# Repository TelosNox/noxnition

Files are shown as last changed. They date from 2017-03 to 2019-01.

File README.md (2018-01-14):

# Feuerwerk Zündmodul + Android App
Selbstbauprojekt für Funkzündmodule

## Zielgruppe
Das Projekt richtet sich an interessierte Privatmenschen mit technischen Kenntnissen, die gerne elektrisch ihr Silvesterfeuerwerk zünden wollen.
Man sollte wissen, wie man grundsätzlich einen Schaltplan liest und wie man an Bauteilen die passenden Pins erkennt (Datenblatt). Und man sollte mit dem Lötkolben umgehen können.

Dieses Projekt richtet sich NICHT an Profis. Wer etwas für professionelle Einsatzzwecke sucht, ist hier leider falsch.
Dennoch darf natürlich gerne reingeschaut werden.

## Eckdaten
#### Zündmodul
- Funkzündmodul mit n x 8 Kanälen
- Manuelle Scharfschaltung
- Elektrische Scharfschaltung
- Durchgangsprüfung der Zünder
- Zündspannung 12V max 7A, Prüfstrom 1,2mA
- Kommunikation über WiFi (WPA gesichert)
- Einfache API über HTTP
#### Android App
- Automatische suche von Modulen
- Direkte Einzelbedienung (Scharfschalten, Durchgangsprüfung, Zündung)
- Feuerwerksplanung mit virtuellen Kanälen (Zusammenfassung mehrerer Kanäle auch unterschiedlicher Module unter einem Namen)
- Ablaufplanung mit Zeitverzögerungen (Sekundenbereich)
- Semiautomatisches Schießen des Feuerwerks

## Motivation
Das Projekt entstand durch mehrere Faktoren. Einerseits war ich gerade für den Kettenheizöler Noxmatic mit dem NodeMCU am experimentieren, andererseits hatte ich gerade ein Silvester hinter mir, an dem wir viele Batterien hatte aber diese manuell zündeten.
Ich hatte die Nase voll vom hin und herlaufen und den Pausen dazwischen. Ich hatte Bock darauf, mein Feuerwerk mal elektisch zu zünden. Keinen Bock hingegen hatte ich daruf, für eine kleine 4 Kanal China Zündanlage schon mindestens 40€ hinzulegen zumal ich ja wusste, wie billig man schon den NodeMCU und die als Treiber nötigen Komponenten bekommt.
Ich hatte auch Bock darauf, sowas mal selbst zu entwickeln, also brachte ich die Idee im Feuerwerk Forum (www.feuerwerk-forum.de) mal zur Sprache und bekam dort viele hilfreiche Ratschläge von Mitgliedern, die elektrotechnisch noch einiges fitter sind, als ich. Für diese Hilfe bin ich sehr Dankbar, denn bei einer Zündanlage geht es auch um Sicherheit und da sollte man nicht am falschen Ende sparen.

## Die Idee
Ich wollte eine Zündanlage für den Selbstbau entwickeln, die möglichst einfach und möglichst günstig nachzubauen und zu bedienen ist. Dabei sollte sie möglichst offen für Erweiterungen sein.
Kommuniziert wird über WLAN, das Protokoll ist HTTP und als Fernsteuerung dient einfach ein beliebiges Android Gerät (hat eigentlich jeder zu Hause).

## Entstehung des Zündmoduls
Ursprünglicher Plan war, dass ein Zündmodul genau 8 Kanäle + eine elektrische Scharfschaltung hat. Der NodeMCU hat genau 9 schaltbare digitale Ausgänge, das reicht für die 8 Kanäle sowie den einen Ausgang für die Scharfschaltung.
An die Ausgänge einfach direkt MosFet als Low Side Schalter dran (ohne weitere Beschaltung) und die Scharfschaltung ebenso als Low Side Schalter für die Gesamtmasse.

Hat so leider nicht funktioniert.
Also gab es folgende Schritte, die zum aktuellen Schaltplan geführt haben.

#### MosFet ordentlich beschalten
Da hier pyrotechnische Gegenstände zum Einsatz kommen, von denen eine gewisse Gefahr ausgeht, muss die Treiberschaltung ordentlich sein. Daher war es gegeben, die MosFet mit einer ordentlichen Schaltung zu versehen.

#### Scharfschaltung mit Low Side Schalter geht nicht
Man kann nicht die Masse eines Low Side MosFet wieder als Busspannung für einen anderen Low Side MosFet verwenden. Das funktioniert so einfach nicht. Also musste eine High Side Schaltung mit einem P-MosFet her. Damit der NodeMCU das aber korret ansteuern kann, wird trotzdem noch ein Low Side gebraucht. Somit war ein zusätzlicher MosFet und Widerstände nötig.
Da P-MosFet keinen so tollen Innenwiderstand wie N-MosFet haben ist der zusätzliche MosFet auch leider nicht ganz so billig.

#### Der NodeMCU zappelt
Leider leider hat so ein NodeMCU 3 Pins, die beim booten kurz zappeln. Die elektrische Scharfschaltung verhindert, dass beim Einschalten irgendwas passieren kann. Wenn allerdings Scharf geschalten ist und dann der Controller einen Reset durchführt, zappeln die Pins und es liegt kurz Zündspannung an.
Meine A-Zünder haben beim Versuch nicht ausgelöst. Trotzdem war das zu unsicher.
Da keine weiteren Pins verfügbar waren und eine Anlage mit nur 5 Kanälen wenig Sinn macht, wurde das Schieberegister hinzugefügt. Somit war das n x 8 Modul geboren, denn die Schaltung erlaubt es jetzt beliebig viele Schieberegister hintereinander zu reihen und so ein beliebiges vielfaches von 8 Kanälen umzusetzen.
Ich selbst habe mir Module mit 8 und 16 Kanälen gebaut.

#### Zu viel Strom!
Da so ein Zünder quasi einen Kurzschluss darstellt und auch Parallelschaltungen von Zündern funktionieren sollen ohne dass Akku oder MosFet abrauchen, wurde noch eine Strombegrenzung eingeführt. Das ist ein simpler großer 10W Draht Keramik Lastwiderstand mit 1,8Ohm. Somit liegt der maximal mögliche Strom bei nominal 12V Spannung (real dann knapp 13) bei ca. 7A.
Natürlich kann das nicht als Dauerstrom betrieben werden. Der P-MosFet erhitzt sich. Für Dauerstrom bräuchte er eine Kühlung.
Der Lastwiderstand ist mit den so anliegenden gut 70W ebenso überfordert, kann das über kurze Zeiträume aber über Wärme abpuffern.
Wen man ganz Safe gehen will, kann man den Widerstand auf 5,6Ohm erhöhen. Damit liegt der Strom bei 2,3A und die Leistung bei 25W. Größere Parallelschaltungen könnten dann aber schwierig werden.

Ergänzt man das alles jetzt noch mit der Spannungsmessung und ein paar Schaltern sowie LEDs und Terminals, kommt man zu dem Schaltplan, der schließlich entstanden ist und umgesetzt wurde.

## Aufbau des Zündmoduls
### Bauteile (Basis)
Die folgenden Bauteile sind nötig, um überhaupt die Grundlage des Moduls zu bilden. Sie bleiben immer gleich, egal wieviele Kanäle man umsetzt.
- 1x NodeMCU V3 (Lolin)
- 2x Kippschalter (am besten unterschiedlich, so dass man Hauptschalter von Zündschalter unterscheiden kann)
- 1x Draht Keramik Lastwiderstand 1,8Ohm 10Watt (R1)
- 1x IRF9540N (Elektrische Scharfschaltung)
- 1x IRF3708 (Elektrische Scharfschaltung)
- 5x R 10k
- 1x R 4,7k
- 2x R 1k
- 1x C 100nF
- 3x LED 12V (Rot, Gelb, Grün)
- 1x Bleiakku 12v (z.B. Ultracell UL1.3-12 den verwende ich)
- 2x Kabelschuhe zum Anschluss des Akkus
- Ausreichend Draht zum verbinden (Mehrfarbig ist Hilfreich) - 0,5mm Querschnitt für Haupt und Zündleitungen, Steuerleitungen dürfen kleiner sein
- Flexible Litze für den Akku und sonstige bewegliche Teile (es ist praktisch, wenn man die Platine aus dem Gehäuse nehmen kann, um bei Bedarf Software aufzuspielen)

### Bauteile je 8 Kanäle
Die folgenden Bauteile sind nötig, um jeweils 8 Kanäle umzusetzen. Diese kann man beliebig vervielfachen.
- 1x 74HC595 (Schieberegister)
- 8x R 100
- 8x R 10k
- 8x Anschlussterminal (Lautsprecherklemmen z.B.)

Will man 16 Kanäle umsetzen, dann braucht man das einfach doppelt, bei 24 Kanäle 3x etc..

### Schaltplan Erläuterung
Hier findet ihr den [Schaltplan](Hardware/KiCad/Zündanalage_Neu/Schematic.pdf)

Ich bin kein Profi, was KiCad angeht, daher ist sicherlich nicht alles optimal.
Für die Schalter hatte ich kein Bauteil gefunden. Daher die gestrichelte Linie und den entprechenden Namen (Hauptschalter, Zündschalter).
Verbunden ist bei Überkreuzungen nur das, was einen Punkt hat.
Die Schieberegister hatten keinen Pin für Vcc, daher ist da ein extra Punkt eingezeichnet und benannt. Das muss an den entsprechenden Pin angeschlossen werden.
Der Schaltplan zeigt den Aufbau für 16 Kanäle. Will man nur 8 Kanäle umsetzen, so lässt man das rechte Schieberegister und alle daran angeschlossenen Treiber einfach weg. Die Leitung, die auf Pin 9 ankommt, muss dann stattdessen beim linken Schieberegister auf Pin 9 angeschlossen werden.
Warum?
Die Schieberegister sind seriell durchgeschleift, indem der serielle Ausgang (Pin 9) des ersten Registers an den Eingang (Pin 14) des nächsten Registers geht. Das LETZTE Register geht dann wieder zurück zum Controller. Will man noch mehr Schieberegister nutzen, so fügt man sie nach diesem Schema einfach zwischen die beiden Register des Schaltplans ein.
Alle anderen Datenleitungen sind als Bus ausgeführt. An jedem Register kommt das selbe an.
Dadurch, dass das letzte Register (bei 8 Kanälen ist das auch das Erste) diesen Ausgang an den Controller zurückgibt, kann der Controller zählen, wieviele Kanäle vorhanden sind. Mit diesem Trick funktioniert die selbe Software mit beliebig vielen Registern. Es wäre sogar möglich, ein einzelnes größeres Register zu verwenden, solange die gleichen Eigenschaften vorliegen.

### Aufbau
Für das Zündmodul gibt es keine vorgefertigte Platine. Es bietet sich an, die Bauteile auf Lochraster zu löten.
Zu aller erst sollte man sich Gedanken machen, wo und wie man alle Bauteile platziert.
Generelle Strategie: An einem Ende Controller und Basisbeschaltung zusammen. Dann mittig Schieberegister und am anderen Ende die MosFet mit Widerstanden.

Wenn man Schritt für Schritt vorgehen will, lötet man zunächst nur den Basisaufbau (nicht übersehen, dass die LED vom Zündschalter auf Masse geht, die Leitung läuft durch die ganzen Treiber). Die rote LED ist für den Hauptschalter gedacht, die gelbe für den Zündkreisschalter und die Grüne zeigt Zündbereitschaft an. Wer möchte mann auch die grüne LED als EIN/AUS nutzen und die rote LED als Warnfarbe für Zündbereitschaft. Die Anleitung geht davon aus, dass Rot für EIN/AUS benutzt wird und beschreibt entsprechend.
Temporär muss man jetzt D2 und D3 (über den vorhandenen 1k Widerstand) überbrücken. Dann kann man Software aufspielen und testen. Die LEDs sollten schon korrekt reagieren (Power LED beim Hauptschalter, Zünd LED beim Zündschalter und die Zündleitungs LED bei Scharfschaltung). Anmerkung: Die Zündleitungs LED leuchtet bei eingeschalteter Power LED schwach. Das ist normal, da Prüfspannung auf der Zündleitung anliegt.
Ebenso sollte die Spannungsanzeige in der App funktionieren (etwa Nennspannung bei eingeschalteter Zündung und ansonsten 2-3V).

Falls an dieser Stelle irgendwas nicht wie beschrieben geht: Fehler suchen.

Anschließend ist es praktisch die MosFet jeweils in Reihen zu setzen, so dass man die Massebeine direkt aufeinander löten kann. Aber Platz lassen, da müssen noch Widerstände hin. Die ebenfalls einlöten, so dass nur noch das Schaltsignal am R100 Widerstand fehlt und der Ausgang zum Anschlussterminal.
Zuletzt die Schieberegister platzieren und verlöten. Nicht vergessen: Die Brücke zwischen D2 und D3 aufmachen und an den Registern korrekt anschließen.

## Bedienung des Zündmoduls
Am Zündmodul gibt es nur 2 Schalter und 3 Leds.
Der Zündkreisschalter sollte beim Einschalten immer ausgeschalten sein (Sicherheit). Dann den Hauptschalter umlegen.
Die rote LED leuchtet, um den Betriebszustand EIN anzuzeigen. Die grüne Zündkreis LED leuchtet schwach (das lässt sich nicht verhindern bzw. wäre nur mit zusätzlichem Aufwand lösbar), das ist normal.
Jetzt ist das Modul Betriebsbereit. Der Zündkreisschalter wird erst dann umgelegt, wenn alle Zünder fertig angeschlossen sind und man sich vergewissert hat, dass die elektrische Scharfschaltung AUS ist (mittels App). Auch die Durchgangsprüfung sollte man sicherheitshalber immer mit ausgeschaltenem Zündkreisschalter machen.

### Konfiguration
Das Modul versucht sich ca. 30sec lang automatisch mit dem konfigurierten WiFi zu verbinden (initial ist noch nichts konfiguriert). Findet es kein passendes Netz, wird es automatisch selbst zum AccessPoint. Per default gelten folgende Daten:
- ssid = "noxnition"
- passwort = "noxnition"
- ip = 192.168.0.128
Das kann im ino Script vorm Einspielen der Software geändert werden.

Nun verbindet man sich mit dem Modul über WiFi, so kann man im Browser einfach die IP des Moduls aufrufen. Es erscheint eine kleine Webseite, mit der das Modul konfiguriert werden kann.
Einzustellen sind:
- Modulname
- SSID
- Passwort

SSID und Passwort beziehen sich hier auf das WiFi, zu dem das Modul sich verbinden soll. Der Modulname MUSS bei Verwendung der App eindeutig sind. Wenn mehrere Module verwendet werden, unterscheidet die App sie anhand ihres Namens.

### Kommunikation
Ist das Modul konfiguriert und loggt sich in ein WiFi ein, so schaltet es in den Bereitschaftsmodus. Jetzt können über HTTP die Funktionen aufgerufen werden.

Allgemein werden alle Aktionen über HTTP GET gesteuert. Für das Feuern eines Kanals wird der Kanal als Parameter übergeben.
Die Antwort ist immer ein simpler Text in Form von Properties.

#### Status
Mit einem HPPT GET und dem Pfad "state" wird der Status abgerufen. Beispiel: `GET http://192.168.0.128/state`
Als Antwort erhält man Spannung und Zündzustand.
- voltage=12.6
- a=1

#### Zündbereitschaft EIN
Mit einem HPPT GET und dem Pfad "arm" wird Zündbereitschaft aktiviert. Beispiel: `GET http://192.168.0.128/arm`
Als Antwort erhält man operation=1 einen Misserfolg gibt es hier nicht.

#### Zündbereitschaft AUS
Mit einem HPPT GET und dem Pfad "disarm" wird Zündbereitschaft aktiviert. Beispiel: `GET http://192.168.0.128/disarm`
Als Antwort erhält man operation=1 einen Misserfolg gibt es hier nicht.

#### Kanal zünden
Mit einem HTTP GET und dem Pfad "fire" wird ein Kanel gezündet. Als Parameter "channel" ist die Kanalnummer zu übergeben. Beispiel: `GET http://192.168.0.128/fire?channel=6`
Als Antwort erhält man Bestätigung und den gefeuerten Kanal
- operation=1
- channel=6

#### Durchgangsprüfung durchführen
Mit einem HTTP GET und dem Pfad "check" wird auf allen Kanälen auf Durchgang geprüft. Beispiel: `GET http://192.168.0.128/check`
Die Anlage stellt nun sicher, dass sie NICHT Zündbereit ist und prüft zusätzlich die anliegende Zündspannung. Geht hier etwas schief, so kommt operation=0 zurück, um den Fehler anzuzeigen. Ansonsten kommt operation=1 und für jeden Kanal die Info, ob er Durchgang hat
- operation=1
- c1=0
- c2=1
- c3=1
- etc...

#### Modulkonfiguraton abfragen
Mit einem HPPT GET und dem Pfad "getConfig" wird die Modulkonfiguration abgefragt. Beispiel: `GET http://192.168.0.128/getConfig`
Als Antwort erhält man den Modulnamen und die Anzahl Kanäle
- name=Fiffi
- channels=16

#### Modul finden
Da die Module über DHCP eine IP bekommen und diese dem Sender somit nicht zwingend bekannt ist, können Module per Broadcast gefunden werden. Jedes Modul reagiert auf UDP Broadcast und sendet als Antwort an den Absender ein UDP Paket mit einer Antwort, wie bei den HTTP Requests. Sie enthält Modulname, Kanäle und den Inhalt der Broadcast Nachricht (zur Identifikation des Requests, wenn zyklisch gepollt wird)-
- name=Fiffi
- channels=16
- request=broadcast135213 (in der Regel sendet man irgend einen Zufallswert oder zählt sequenziell hoch)

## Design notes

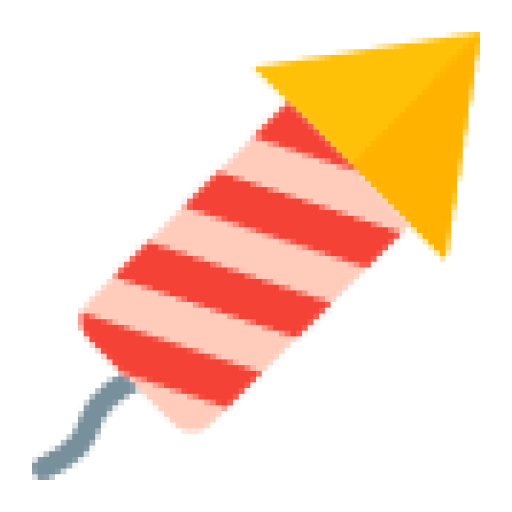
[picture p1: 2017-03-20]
Android/Noxnition/ic_launcher-web.png

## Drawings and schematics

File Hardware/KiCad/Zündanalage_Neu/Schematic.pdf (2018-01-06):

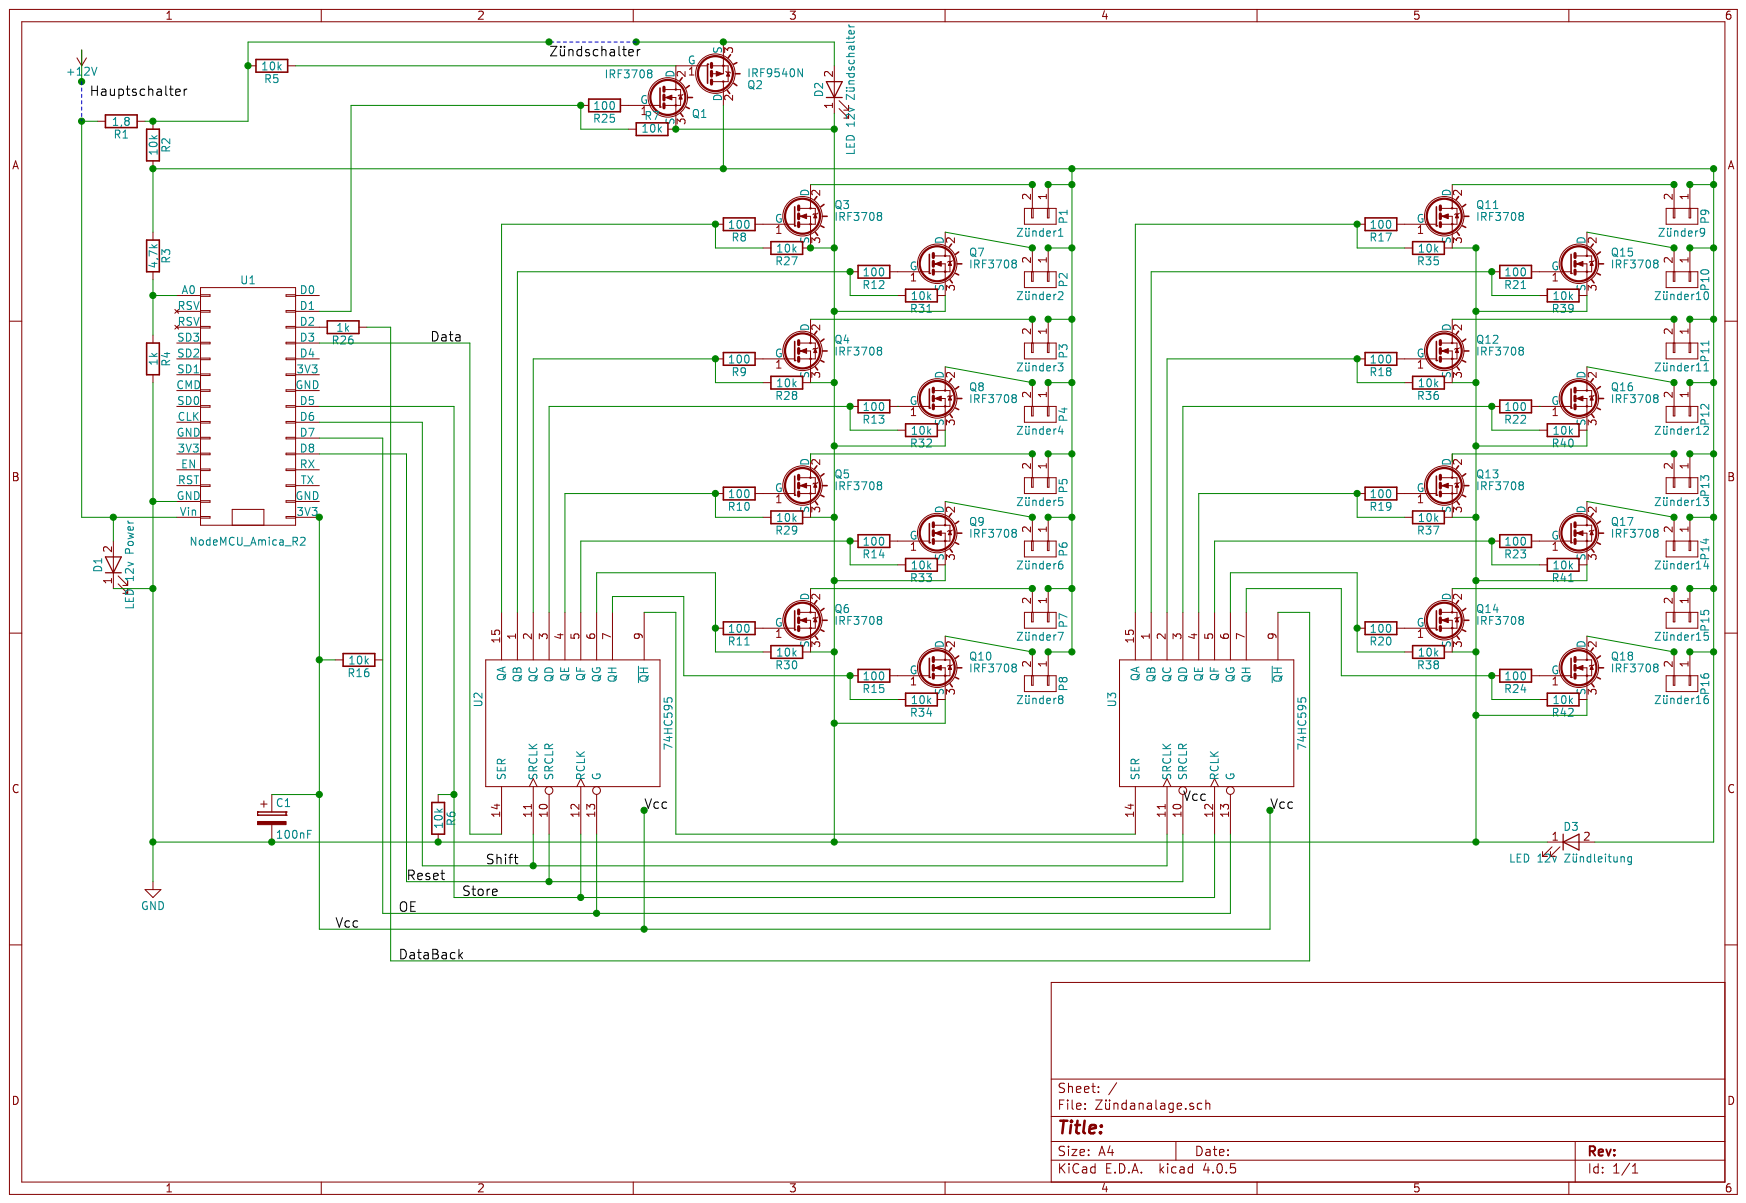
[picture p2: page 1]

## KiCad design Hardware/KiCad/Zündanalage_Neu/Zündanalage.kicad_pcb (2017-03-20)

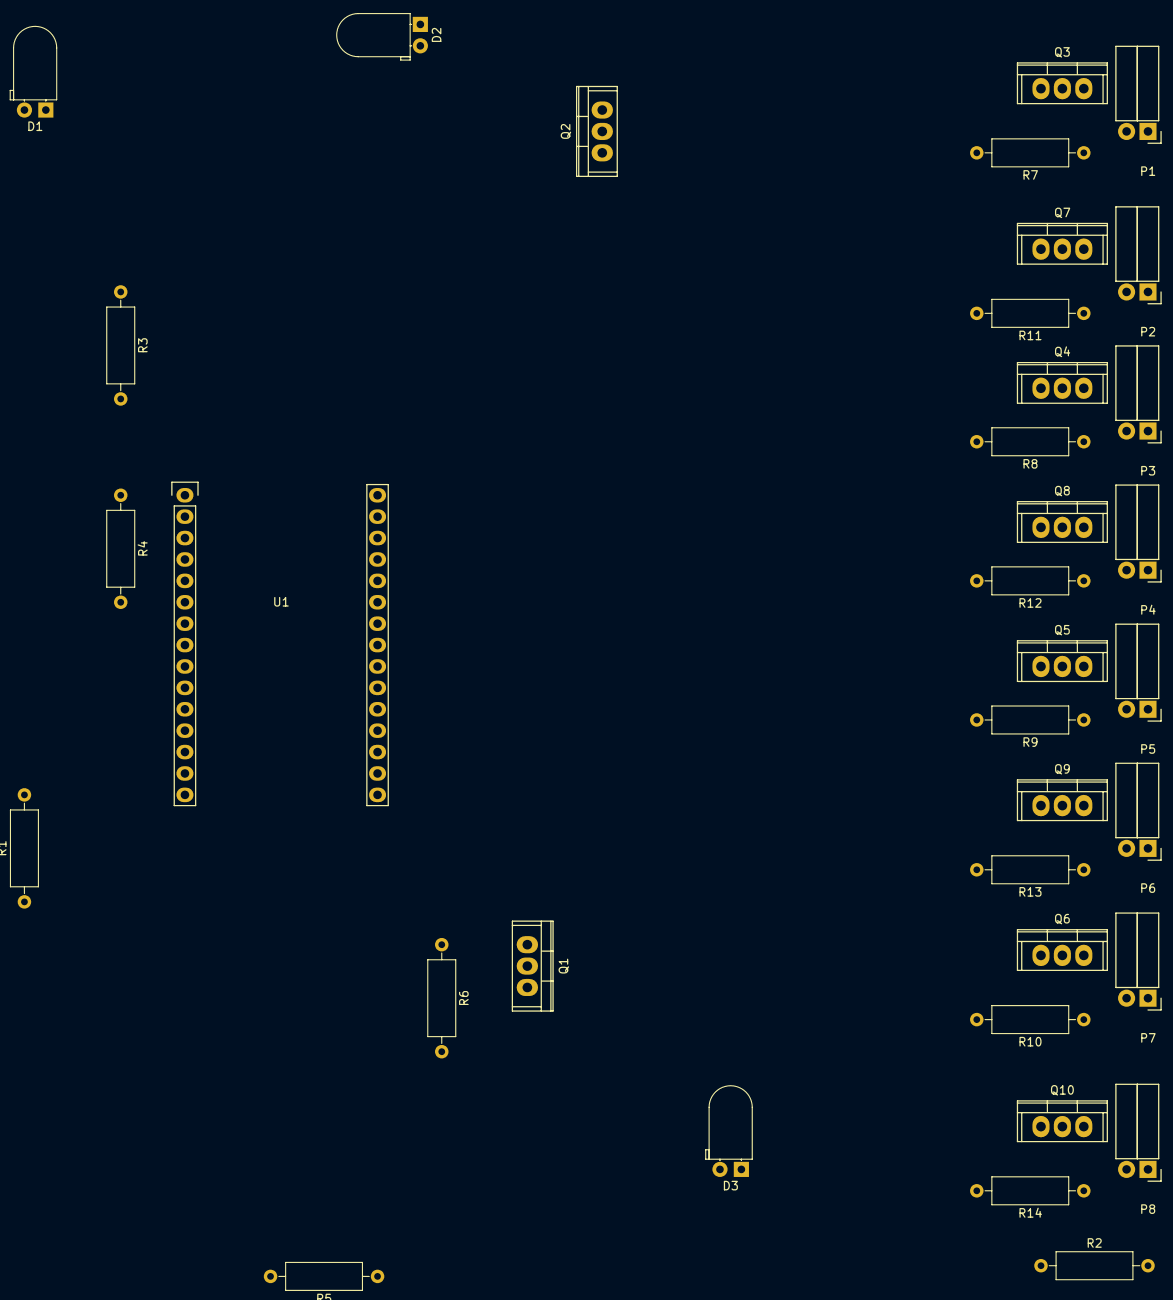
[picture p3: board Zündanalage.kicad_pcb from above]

Board: 2 copper layers, 36 parts (0 on the bottom side), 24 nets, no tracks yet.

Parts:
D1: LED 12v Power; LED_D5.0mm_Horicontal_O1.27mm
D2: LED 12v Zündschalter; LED_D5.0mm_Horicontal_O1.27mm
D3: LED 12v Zündleitung; LED_D5.0mm_Horicontal_O1.27mm
P1: Zünder1; Socket_Strip_Angled_1x02
P2: Zünder2; Socket_Strip_Angled_1x02
P3: Zünder3; Socket_Strip_Angled_1x02
P4: Zünder4; Socket_Strip_Angled_1x02
P5: Zünder5; Socket_Strip_Angled_1x02
P6: Zünder6; Socket_Strip_Angled_1x02
P7: Zünder7; Socket_Strip_Angled_1x02
P8: Zünder8; Socket_Strip_Angled_1x02
Q1, Q3, Q4, Q5, Q6, Q7, Q8, Q9, Q10: IRF3708; TO-220
Q2: IRF9540N; TO-220
R1: 1,8; R_Axial_DIN0309_L9.0mm_D3.2mm_P12.70mm_Horizontal
R2, R5, R6, R7, R8, R9, R10, R11, R12, R13, R14: 10k; R_Axial_DIN0309_L9.0mm_D3.2mm_P12.70mm_Horizontal
R3: 4,7k; R_Axial_DIN0309_L9.0mm_D3.2mm_P12.70mm_Horizontal
R4: 1k; R_Axial_DIN0309_L9.0mm_D3.2mm_P12.70mm_Horizontal
U1: NodeMCU_Amica_R2

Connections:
GND: D1.1, D2.1, D3.1, Q1.3, Q3.3, Q4.3, Q5.3, Q6.3, Q7.3, Q8.3, Q9.3, Q10.3, R4.2, R6.2, R7.1, R8.1, R9.1, R10.1, R11.1, R12.1, R13.1, R14.1, U1.14
unnamed: D1.2, R1.2, U1.15
unnamed: D2.2, Q2.3
unnamed: D3.2, P1.1, P2.1, P3.1, P4.1, P5.1, P6.1, P7.1, P8.1, Q2.2, R2.2, R3.1
unnamed: P1.2, Q3.2
unnamed: P2.2, Q7.2
unnamed: P3.2, Q4.2
unnamed: P4.2, Q8.2
unnamed: P5.2, Q5.2
unnamed: P6.2, Q9.2
unnamed: P7.2, Q6.2
unnamed: P8.2, Q10.2
unnamed: Q1.1, R6.1, U1.22
unnamed: Q1.2, Q2.1, R5.1
unnamed: Q3.1, R7.2, U1.29
unnamed: Q4.1, R8.2, U1.21
unnamed: Q5.1, R9.2, U1.23
unnamed: Q6.1, R10.2, U1.27
unnamed: Q7.1, R11.2, U1.28
unnamed: Q8.1, R12.2, U1.20
unnamed: Q9.1, R13.2, U1.30
unnamed: Q10.1, R14.2, U1.26
unnamed: R1.1, R2.1, R5.2
unnamed: R3.2, R4.1, U1.1

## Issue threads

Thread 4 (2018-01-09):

Geplantes Feuerwerk ohne Aktionen lässt App Abstürzen

TelosNox, 2018-01-09:
Wenn ein geplantes Feuerwerk keine Aktionen hat und man Start drückt, dann stürzt die App ab

TelosNox, 2018-01-14:
Start wird jetzt abgelehnt, wenn keine fire actions existieren

Closed 2018-01-14.

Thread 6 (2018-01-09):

Bereits zugewiesene Triggergruppen nicht mehr anzeigen

TelosNox, 2018-01-09:
Beim Hinzufügen von Triggergruppen zum Abschussplan, werden immer alle Triggergruppen angeboten. Hier sollten nur die auftauchen, die noch nicht hinzugefügt wurden.

TelosNox, 2018-01-14:
Es werden nur noch Triggergruppen angezeigt, die noch nicht zugewiesen sind.

Closed 2018-01-14.

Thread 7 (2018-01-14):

Modulerkennung ändern

TelosNox, 2018-01-14:
Aktuell wird zyklisch ein Broadcast gesendet, um Module zu finden.
Das soll so geändert werden, dass die Modulsuche nur auf Befehl durchgeführt wird. Die Prüfung, ob ein Modul noch online ist, soll über die Statusabfrage erfolgen. Wenn das Modul hier mehrfach nicht reagiert, gilt es als offline.

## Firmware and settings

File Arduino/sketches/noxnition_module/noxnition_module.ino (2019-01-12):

#include <EEPROM.h>
#include <ESP8266WiFi.h>
#include <ESP8266WebServer.h>
#include <WiFiUdp.h>

#define fireTimeMillis 500

const char* config_ssid = "noxnition";
const char* config_password = "noxnition";

const int pinMain = D1;
const int pinData = D3;
const int pinDataBack = D2;
const int pinShift = D6;
const int pinReset = D8;
const int pinOE = D7;
const int pinStore = D5;

ESP8266WebServer server(80);

long *channelTimers = 0;
boolean *channelStates = 0;

String ssid;
String password;
String moduleName;

float voltage;

boolean armed = false;

int channels = 0;

WiFiUDP Udp;
unsigned int localPort = 2390; 
char incomingPacket[255];

void setup() {
  initPins();

  delay(100);

  channels = getChannelCount();
  channelStates = new boolean[channels];
  channelTimers = new long[channels];
  for(int i=0; i < channels; i++) {
    channelTimers[i] = 0;
    channelStates[i] = LOW;
  }

  digitalWrite(pinReset, LOW);

  Serial.begin(115200);
  EEPROM.begin(512);
  delay(10);
  digitalWrite(pinReset, HIGH);
  setRegisterOutput();
  digitalWrite(pinOE, LOW);

  String esid;
  for (int i = 0; i < 32; ++i) {
    esid += char(EEPROM.read(i));
  }
  ssid = esid.c_str();
  Serial.print("SSID: ");
  Serial.println(ssid);
  Serial.println("Reading EEPROM pass");
  String epass = "";
  for (int i = 32; i < 96; ++i) {
    epass += char(EEPROM.read(i));
  }
  password = epass.c_str();
  Serial.print("PASS: ");
  Serial.println(password);  
  Serial.println("Reading EEPROM name");
  String ename = "";
  for (int i = 96; i < 128; ++i) {
    ename += char(EEPROM.read(i));
  }
  Serial.print("NAME: ");
  Serial.println(ename);  

  moduleName = ename.c_str();

  Serial.print("channels: ");
  Serial.println(channels);
  
  // Connect to WiFi network
  Serial.println();

  boolean clientMode = initWifiClient(ssid, password);
  
  Serial.println(WiFi.localIP());
  
  if (!clientMode) {
    Serial.println("AP Mode for Settings");
    initWifiAP();
    initConfigServer();
  } else {
    Serial.println("Module Mode");
    initModuleServer();
  }

  Udp.begin(localPort);
}

void initConfigServer() {
  server.begin();
  server.on("/", settings);
}

void initModuleServer() {
  server.begin();
  server.on("/state", getStatus);
  server.on("/arm", arm);
  server.on("/disarm", disarm);
  server.on("/fire", fire);
  server.on("/check", check);
  server.on("/getConfig", getConfig);
}

void getConfig() {
  String temp = "name=";
  temp += moduleName;
  temp += "\nchannels=";
  temp += channels;
  server.send(200, "application/json", temp);
}

boolean writeSetting(String qsid, String qpass, String qname) {
  if (qsid.length() > 0 && qpass.length() > 0 && qname.length() > 0) {
    Serial.println("clearing eeprom");
    for (int i = 0; i < 128; ++i) { EEPROM.write(i, 0); }
    Serial.println(qsid);
    Serial.println("");
    Serial.println(qpass);
    Serial.println("");
    
    Serial.println("writing eeprom ssid:");
    for (int i = 0; i < qsid.length(); ++i) {
      EEPROM.write(i, qsid[i]);
      Serial.print("Wrote: ");
      Serial.println(qsid[i]); 
    }
    Serial.println("writing eeprom pass:"); 
    for (int i = 0; i < qpass.length(); ++i) {
      EEPROM.write(32+i, qpass[i]);
      Serial.print("Wrote: ");
      Serial.println(qpass[i]); 
    }    
  
    Serial.println("writing eeprom name:"); 
    for (int i = 0; i < qname.length(); ++i) {
      EEPROM.write(96+i, qname[i]);
      Serial.print("Wrote: ");
      Serial.println(qname[i]); 
    }    

    moduleName = qname;
    password = qpass;
    ssid = qsid;
  
    EEPROM.commit();
    return true;
  }
  return false;
}

void settings() {
  String action = server.arg("action");
  String add = "";
  if (action == "save") {
    String qsid = server.arg("ssid");
    String qpass = server.arg("pass");
    String qname = server.arg("name");
    boolean success = writeSetting(qsid, qpass, qname);
    if (success) {
      add += "{\"Success\":\"saved to eeprom... reset to boot into new wifi\"}";
    }
  }
  String temp = getSettingsHtml();
  temp += add;
  server.send(200, "text/html", temp);
}

String getSettingsHtml() {
  String temp = "<html><body><form action=\"\" method=\"post\"><input type=\"hidden\" name=\"action\" id=\"action\" value=\"save\"><table border=\"1\" cellspacing=\"0\"><tr><td>Name</td><td><input type=\"text\" name=\"name\" id=\"name\" maxlength=\"40\" value=\"";
  temp += moduleName;
  temp += "\"></td></tr><tr><td>SSID</td><td><input type=\"text\" name=\"ssid\" id=\"ssid\" maxlength=\"40\" value=\"";
  temp += ssid;
  temp += "\"></td></tr><tr><td>Password</td><td><input type=\"text\" name=\"pass\" id=\"pass\" maxlength=\"40\" value=\"";
  temp += password;
  temp += "\"></td></tr></table><button type=\"submit\">Send</button></form></body></html>";
  return temp;
}

void initPins() {
  pinMode(pinMain, OUTPUT);
  digitalWrite(pinMain, LOW);

  pinMode(pinData, OUTPUT);
  digitalWrite(pinData, LOW);

  pinMode(pinDataBack, INPUT);
  digitalWrite(pinDataBack, LOW);

  pinMode(pinShift, OUTPUT);
  digitalWrite(pinShift, LOW);

  pinMode(pinReset, OUTPUT);
  digitalWrite(pinReset, HIGH);

  pinMode(pinOE, OUTPUT);
  digitalWrite(pinOE, HIGH);

  pinMode(pinStore, OUTPUT);
  digitalWrite(pinStore, LOW);
}

int getChannelCount() {
  digitalWrite(pinReset, LOW);
  digitalWrite(pinReset, HIGH);
  boolean state = LOW;
  int channelCount = 0;
  digitalWrite(pinData, HIGH);
  while(!state) {
    channelCount++;
    digitalWrite(pinShift, LOW);
    digitalWrite(pinShift, HIGH);
    state = digitalRead(pinDataBack);
  }
  digitalWrite(pinData, LOW);
  return channelCount;
}

void initWifiAP() {
  WiFi.disconnect(); 
  WiFi.mode(WIFI_AP);
  IPAddress ip(192,168,0,128);  //Node static IP
  IPAddress gateway(192,168,0,128);
  IPAddress subnet(255,255,255,0);
  WiFi.softAPConfig(ip, gateway, subnet);   // subnet FF FF FF 00
  WiFi.softAP(config_ssid, config_password);
}

boolean initWifiClient(String ssid, String password) {
  WiFi.disconnect(); 
  WiFi.mode(WIFI_STA);
  WiFi.begin(ssid.c_str(), password.c_str());
  int retry = 0;
  while (WiFi.status() != WL_CONNECTED) {
    retry++;
    if (retry > 50) {
      return false;
    }
    delay(500);
  }
  return true;
}

void fire() {
  String channelString = server.arg("channel");
  int channel = channelString.toInt();
  Serial.print("channel to fire: ");
  Serial.println(channel);
  int index = channel-1;
  long fireEnd = millis() + fireTimeMillis;
  channelTimers[index] = fireEnd;
  channelStates[index] = HIGH;
  setRegisterOutput();
  String temp = "operation=1\nchannel=";
  temp += channel;
  server.send(200, "application/json", temp);

}

void setRegisterOutput() {
  digitalWrite(pinStore, LOW);

  for(int i=channels-1; i >= 0; i--) {
    digitalWrite(pinShift, LOW);
    digitalWrite(pinData, channelStates[i]);
    digitalWrite(pinShift, HIGH);
  }
  digitalWrite(pinStore, HIGH);
}

void arm() {
  armInternal(true);

  server.send(200, "application/json", "operation=1");
}

void disarm() {
  armInternal(false);

  server.send(200, "application/json", "operation=1");
}

void armInternal(boolean arm) {
  armed = arm;
  digitalWrite(pinMain, armed);
}

void check() {
  for(int i=0; i < channels; i++) {
    channelStates[i] = LOW;
  }
  setRegisterOutput();
  
  boolean wasArmed = armed;
  if (armed) {
    armInternal(false);
    delay(20);
  }
  int voltageIn = analogRead(A0);
  if (voltageIn > 200) {
    server.send(200, "application/json", "operation=0");
    return;
  }

  if (voltageIn < 50) {
    server.send(200, "application/json", "operation=0");
    return;
  }

  String temp = "operation=1";

  for(int i=0; i < channels; i++) {
    boolean pinState = false;
    temp += "\nc";
    temp += i+1;
    temp += "=";
    int pinVoltageIn = analogRead(A0);
    if (pinVoltageIn > 50) {
      channelStates[i] = HIGH;
      setRegisterOutput();
      delay(5);
      pinVoltageIn = analogRead(A0);
      pinState = pinVoltageIn < 30;
      channelStates[i] = LOW;
      setRegisterOutput();
      delay(5);
    }
    temp += pinState;
  }
  server.send(200, "application/json", temp);
}

void getStatus() {
  String temp = "voltage=";
  temp += voltage;
  temp += "\n";
  temp += "a=";
  temp += armed;

  for(int i=0; i < channels; i++) {
    temp += "\n";
    temp += "c";
    temp += i+1;
    temp += "=";
    temp += channelStates[i];
  }

  server.send(200, "application/json", temp);
}

void processVoltage() {
  static long nextMillis = 0;
  static const float factor = 3.3 * 5.85;

  long currentMillis = millis();
  if (currentMillis > nextMillis) {
    float averageMes = average(analogRead(A0));
    voltage = factor * averageMes / 1024;
    nextMillis = currentMillis + 50;
  }
}

float average(int value) {
  static const int numberOfValues = 10;
  static int values[numberOfValues], counter=0;
  
  int sum=0;
  values[counter] = value;
  for(int i=0; i < numberOfValues; i++) {
    sum += values[i];
  }
  counter++;
  if(counter >= numberOfValues) {
    counter=0;
  }
  return (float) sum / numberOfValues; 
}

void handleFire() {
  long currentMillis = millis();
  for(int i=0; i < channels; i++) {
    long fireEnd = channelTimers[i];
    if (fireEnd != 0 && currentMillis > fireEnd) {
      channelTimers[i] = 0;
      channelStates[i] = LOW;
      setRegisterOutput();
    }
  }
}
 
void loop() {
  int packetSize = Udp.parsePacket();
  if (packetSize) {
    int len = Udp.read(incomingPacket, 255);
    if (len > 0) {
      incomingPacket[len] = 0;
    }
    Serial.println("answer broadcast");
    WiFiClient client;
    if (client.connect(Udp.remoteIP().toString().c_str(), 2410)) {
      String temp = "name=";
      temp += moduleName;
      temp += "\nchannels=";
      temp += channels;
      temp += "\nrequest=";
      temp += incomingPacket;
      client.print(temp);
    }
    client.stop();
  }
  processVoltage();
  handleFire();
  server.handleClient();
}

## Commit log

2017-03-20 Add KiCad sketches
    [Zündanalage.kicad_pcb, Zündanalage.sch]
2017-12-23 Broadcast fix + Semi automatic mode
    commit missing files
    [noxnition_module.ino]
2018-01-03 Rework persistence, some UI and Bugfix
    - Persistence now uses JSON, so it is easier to change/enhance
    - Planned Firework is not accessed by button anymore. Instead the main
    screen is swiped
    - Add capability to retry ignition in planned firework if ignition
    command is not confirmed
2018-01-05 Rework Firework planning
    Introduced Fire Trigger Groups which can assign multiple channels to one
    single item.
    Firework planning is currently broken. No Fire Actions can be assigned
    because in future they will be based on the new Trigger Groups
2018-01-06 Add Schematic as pdf
2018-01-07 Improve planned firework execution
    Set all required modules into armed state and check if the state has
    been switched
2019-01-12 Improve Communication Structure
    Remove own created threads in communication and use async task instead.
    Calculate average ping of modules instead of single value and allow
    longer connection timeout.
